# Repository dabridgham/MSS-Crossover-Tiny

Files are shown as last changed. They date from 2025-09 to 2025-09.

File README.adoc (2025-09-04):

= MSS Crossover

A KiCad project for a circuit board that implements an
https://www.modularsignalsystem.info/index.html[MSS] Detection node
(aka Crossover node).  It includes the block detection circuit and the
crossover wiring between two RJ45 connectors.

The block detection is implemented with a resistor as the current
sense element and then an ATtiny to do the math.  The board includes
the bridge rectifier so it can be powered off the ACC bus and it uses
optoisolators to drive the MSS line.

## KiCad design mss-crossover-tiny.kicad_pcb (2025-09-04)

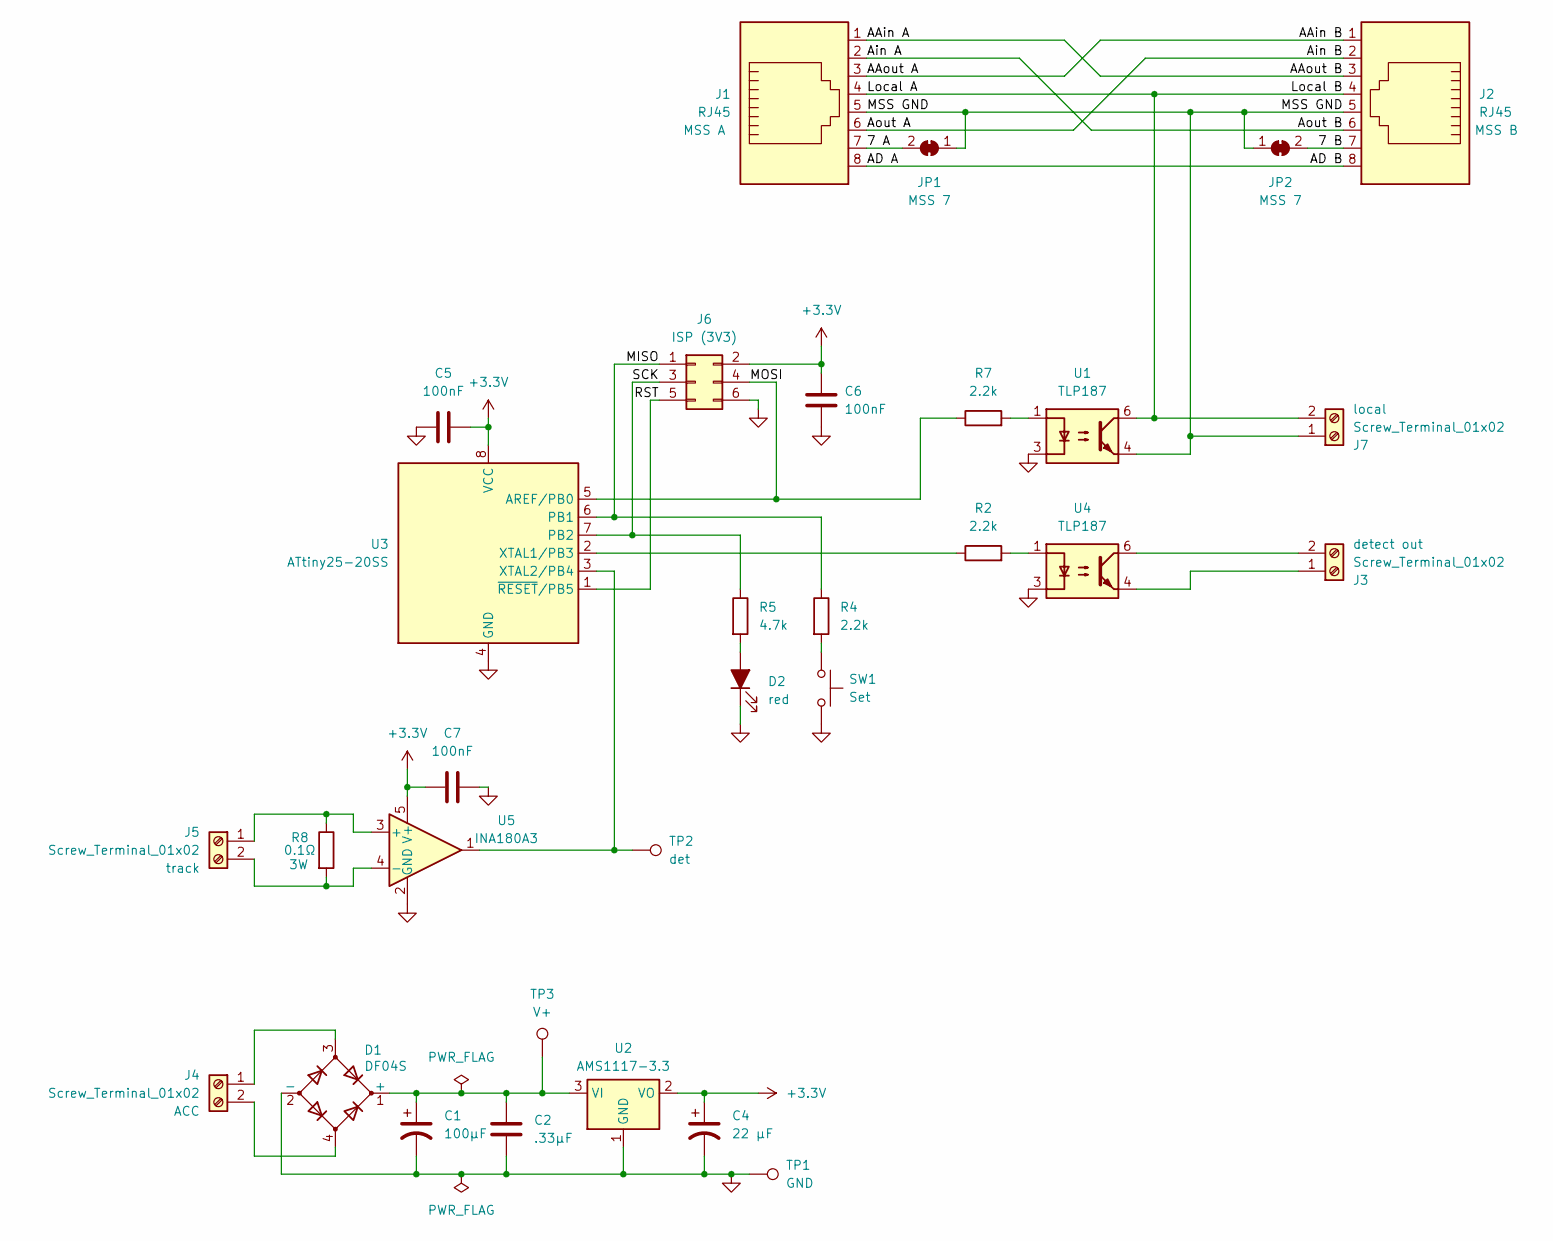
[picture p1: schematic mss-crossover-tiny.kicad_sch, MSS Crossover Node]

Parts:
C1: 100µF; CP_Elec_6.3x7.7; MPN EEV107M035A9HAA; JLCPCB Part C3338
C2: .33µF; C_0805_2012Metric_Pad1.18x1.45mm_HandSolder; MPN CL21B334KBFNNNE; JLCPCB Part C1737
C4: 22 µF; CP_EIA-3216-18_Kemet-A_Pad1.58x1.35mm_HandSolder; JLCPCB Part C7183
C5, C6, C7: 100nF; C_0805_2012Metric_Pad1.18x1.45mm_HandSolder; MPN CL21B104KBCNNNC
D1: DF04S; Diode_Bridge_Vishay_DFS; MPN DF04S; JLCPCB Part C5185986
D2: red; LED_0805_2012Metric_Pad1.15x1.40mm_HandSolder; MPN LTST-C170KRKT; JLCPCB Part C84256
J1, J2: RJ45; MJ3221-88; MPN MJ3221-88
J3, J4, J5, J7: Screw_Terminal_01x02; CUI_TB003-500-P02BE; MPN 691210910002
J6: ISP (3V3); Tag-Connect_TC2030-IDC-NL_2x03_P1.27mm_Vertical
JP1, JP2: MSS 7; SolderJumper-2_P1.3mm_Bridged_RoundedPad1.0x1.5mm
R2, R4, R7: 2.2k; R_0805_2012Metric_Pad1.20x1.40mm_HandSolder; MPN RC0805FR-102K2L
R5: 4.7k; R_0805_2012Metric_Pad1.20x1.40mm_HandSolder; MPN RC0805FR-104K7L
R8: 0.1Ω; R_2512_6332Metric; MPN CRA2512-FZ-R100ELF; JLCPCB Part C7419997
SW1: Set; SW_Push_1P1T_NO_CK_KMR2; MPN KMR211NG LFS; JLCPCB Part C72443
TP1: GND; TestPoint_THTPad_1.5x1.5mm_Drill0.7mm
TP2: det; TestPoint_THTPad_1.5x1.5mm_Drill0.7mm
TP3: V+; TestPoint_THTPad_1.5x1.5mm_Drill0.7mm
U1, U4: TLP187; SOIC-4_4.55x3.7mm_P2.54mm; MPN TLP187; JLCPCB Part C393886
U2: AMS1117-3.3; SOT-223-3_TabPin2; MPN AMS1117-3.3
U3: ATtiny25-20SS; SOIC-8_3.9x4.9mm_P1.27mm; MPN ATtiny25-20SSU
U5: INA180A3; SOT-23-5; MPN INA180A1IDBVR

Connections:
+3.3V: C4.1, C5.2, C6.2, C7.1, J6.2, U2.2 (VO), U3.8 (VCC), U5.5 (V+)
/7 A: J1.7, JP1.2 (B)
/7 B: J2.7, JP2.2 (B)
/AAin A: J1.1, J2.3
/AAin B: J1.3, J2.1
/AD A: J1.8, J2.8
/Ain A: J1.2, J2.6
/Ain B: J1.6, J2.2
/Local A: J1.4, J2.4, J7.2, U1.6
/MISO: J6.1, R4.1, U3.6 (PB1)
/MOSI: J6.4, R7.1, U3.5 (AREF/PB0)
/MSS GND: J1.5, J2.5, J7.1, JP1.1 (A), JP2.1 (A), U1.4
/RST: J6.5, U3.1 (~RESET/PB5)
/SCK: J6.3, R5.1, U3.7 (PB2)
GND: C1.2, C2.2, C4.2, C5.1, C6.1, C7.2, D1.2 (-), D2.1 (K), J6.6, SW1.1, TP1.1, U1.3, U2.1 (GND), U3.4 (GND), U4.3, U5.2 (GND)
unnamed: C1.1, C2.1, D1.1 (+), TP3.1, U2.3 (VI)
unnamed: D2.2 (A), R5.2
unnamed: J3.1, U4.4
unnamed: J3.2, U4.6
unnamed: D1.3, J4.1
unnamed: D1.4, J4.2
unnamed: J5.1, R8.1, U5.3 (+)
unnamed: J5.2, R8.2, U5.4 (-)
unnamed: R2.2, U4.1
unnamed: R4.2, SW1.2
unnamed: R7.2, U1.1
unnamed: R2.1, U3.2 (XTAL1/PB3)
unnamed: TP2.1, U3.3 (XTAL2/PB4), U5.1

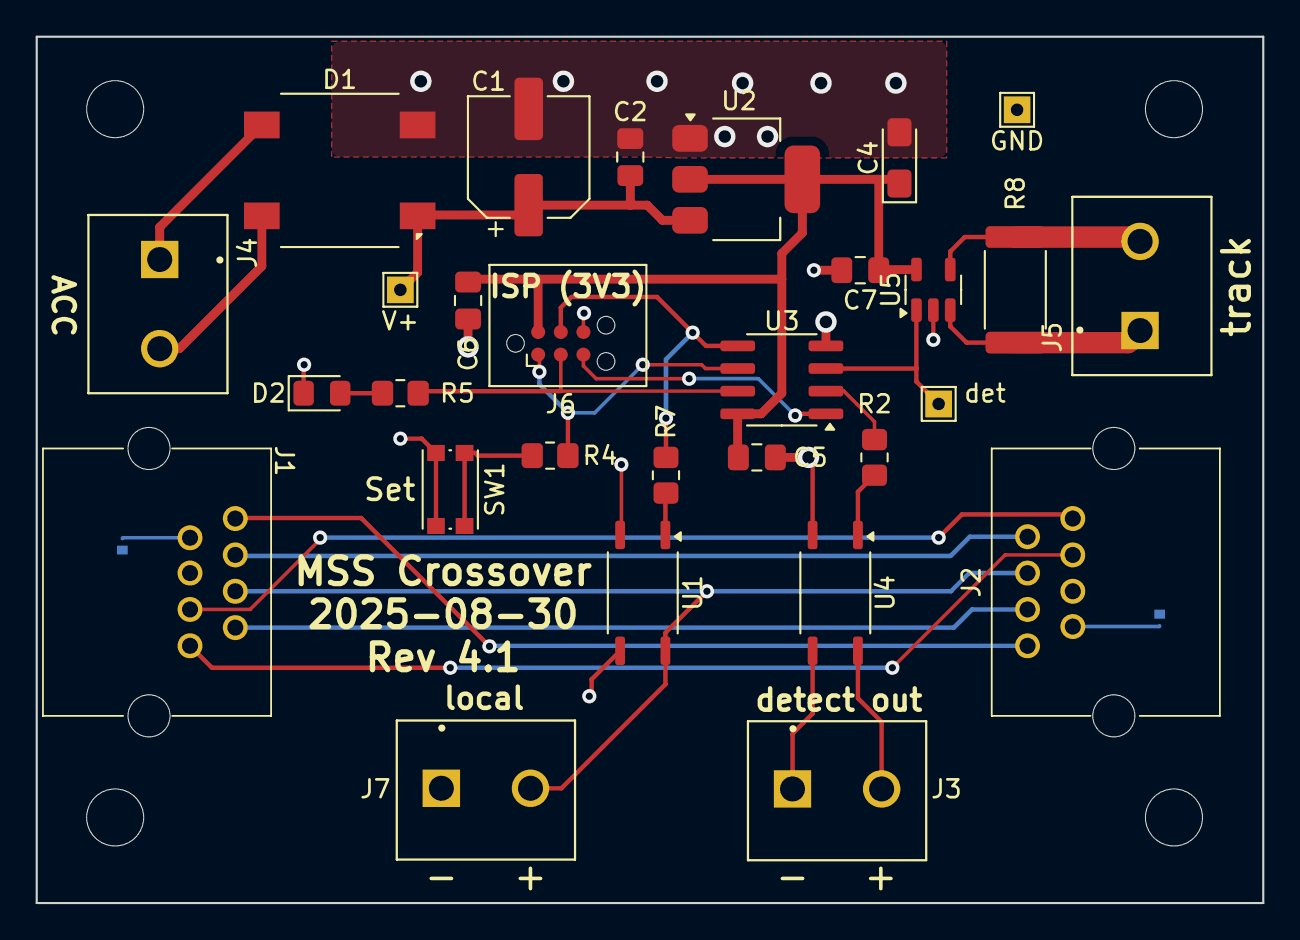
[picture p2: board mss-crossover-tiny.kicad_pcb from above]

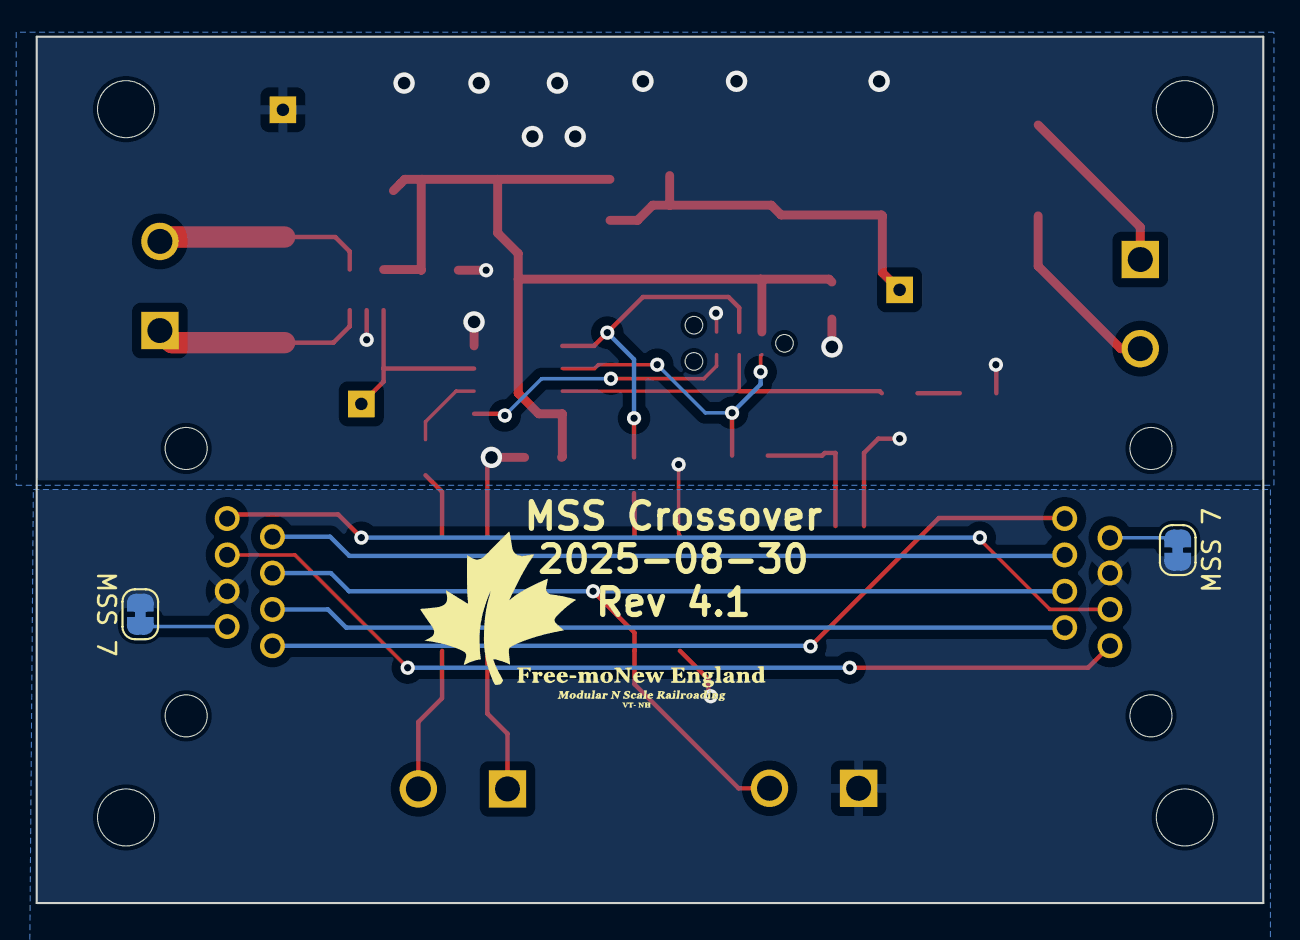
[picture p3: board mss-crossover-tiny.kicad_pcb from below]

Board: 2 copper layers, 68.8 x 48.6 mm, 31 parts (2 on the bottom side), 28 nets.

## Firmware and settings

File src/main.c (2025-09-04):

#define F_CPU 1000000UL		/* default internal clock is 1 MHz (8 MHz div 8) */
#include <avr/io.h>
#include <util/delay.h>
#include <avr/io.h>
#include <avr/interrupt.h>
#include <util/atomic.h>
#include <avr/eeprom.h>

 
#define bit(n) (1<<n)
#define bit_set(reg, bit) { reg |= (1<<bit); }
#define bit_clear(reg, bit) { reg &= ~(1<<bit); }

#define LED_ON() { bit_set(PORTB, PORTB2) }
#define LED_OFF() { bit_clear(PORTB, PORTB2) }

/* Control the LED, MSS, and detect outputs */
#define OUTPUT_ON() { PORTB |= bit(PORTB3) | bit(PORTB2) | bit(PORTB0); }
#define OUTPUT_OFF() { PORTB &= ~(bit(PORTB3) | bit(PORTB2) | bit(PORTB0)); }

#define BUTTON_PUSHED() (!bit_is_set(PINB, DDB1))

const int16_t attack = 100;
const int16_t decay = 10;
const int32_t filtern = 980;	/* filter numerator */
const int32_t filterd = 1000;	/* filter denominator */
const unsigned int timeout = 2000; /* 2 seconds */
const unsigned int sample_time = 2000; /* 2 seconds */
#define filter(old, new) (((old * filtern)/filterd) + (((new * (filterd-filtern))/filterd)))

uint16_t *threshold_p = 0; /* EEPROM address for the saved threshold */

/*
 * Timer interrupt code to implement a millis() function.
 */
volatile unsigned long timer0_millis = 0;

// Initialize the timer for 1ms interrupts
void millis_init(void) {
    // Set Timer0 to CTC mode with a prescaler of 64
    TCCR0A = (1 << WGM01);
    TCCR0B = (1 << CS01) | (1 << CS00); // Prescaler 64

    // Set compare value for 1ms at 16MHz: (16,000,000 / 64) / 1000 = 250
    // Set compare value for 1ms at 1MHz: (1,000,000 / 64) / 1000 = 16
    OCR0A = 16;

    // Enable compare match interrupt
    TIMSK |= (1 << OCIE0A);

    // Enable global interrupts
    sei();
}

// Timer0 compare match interrupt service routine
ISR(TIMER0_COMPA_vect) {
    timer0_millis++;
}

// Return the number of milliseconds since the program started
unsigned long millis(void) {
    unsigned long m;
    ATOMIC_BLOCK(ATOMIC_FORCEON) {
        m = timer0_millis;
    }
    return m;
}   

/* Setup the ADC */
void adc_init()
{
  ADMUX =		  // Vref = Vcc
    bit(ADLAR) |	  // left shifted
    0x2;		  // input is single-ended PB4 (ADC2)
  DIDR0 = bit(ADC2D);	  // disable the digital inputs on ADC2
  ADCSRB = bit(BIN);	  // bipolar input mode, free running mode
  ADCSRA = bit(ADEN) |	  // enable ADC
    //    bit(ADSC) |		// start conversion
    //    bit(ADATE) |		// auto trigger enable
    bit(ADPS2) | bit(ADPS1) | bit(ADPS0); // scale ADC clock by 128

  /* setup the ADC */
  ADMUX =		  // Vref = Vcc
    bit(ADLAR) |	  // left shifted
    0x2;		  // input is single-ended PB4 (ADC2)
  DIDR0 = bit(ADC2D);	  // disable the digital inputs on ADC2
  ADCSRB = bit(BIN);	  // bipolar input mode, free running mode
  ADCSRA = bit(ADEN) |	  // enable ADC
    //    bit(ADSC) |		// start conversion
    //    bit(ADATE) |		// auto trigger enable
    bit(ADPS2) | bit(ADPS1) | bit(ADPS0); // scale ADC clock by 128
}

/* Read the A/D Converter */
uint16_t read_adc()
{
  uint8_t c_low, c_hi;

  ADCSRA |= bit(ADSC);		   /* start conversion */
  while (bit_is_set(ADCSRA, ADSC)) /* wait for ADC to finish */
    ;				   /* should probably time out */

  /* must read low then high, per the datasheet */
  c_low = ADCL;
  c_hi = ADCH;
  return (c_hi << 8) | c_low;
}

int main()
{
  int16_t amps = 0,
    hi_amps = 0,
    threshold = 1000,
    setting_threshold = 0;
  unsigned long last_hi = 0,
    current_millis = 0;

  threshold = eeprom_read_word(threshold_p); /* read the stored threshold */

  millis_init();		/* enable the millisecond counter */

  // Set pins 5 (PB0), 7 (PB2), and 2 (PB3) as outputs, all others
  // inputs
  DDRB = bit(DDB0) | bit(DDB2) | bit(DDB3); 
  PORTB |= bit(DDB1);		/* enable pullup on pin 6 (PB1) for the pushbutton */

  adc_init();			/* setup the ADC */

  while (1) {
    current_millis = millis();
    if (setting_threshold) {
      if ((current_millis - last_hi) > sample_time) {
	threshold = (hi_amps * 15) / 10; /* set threshold 50% higher */
	eeprom_write_word(threshold_p, threshold);
	setting_threshold = 0;
	last_hi = 0;
	LED_OFF();
      } else {
	/* set hi_amps to the highest reading during the sample period */
	amps = read_adc();
	if (amps > hi_amps)
	  hi_amps = amps;
      }
    } else {
      if (BUTTON_PUSHED()) {
	setting_threshold = 1;
	last_hi = current_millis; /* use last_hi for the sample timeout */
	hi_amps = 0;
	LED_ON();
      } else {
	amps = read_adc();

	/* values greater than the threshold update the time */
	if (amps > threshold)
	  last_hi = current_millis;

	/* if the last high value was more recent than timeout, set detection outputs */
	if ((current_millis - last_hi) < timeout) {
	  OUTPUT_ON();
	} else {
	  OUTPUT_OFF();
	}

	_delay_ms(1);
      }
    }
  }
}

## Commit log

2023-11-03 Initial commit. The first prototype board is built and the software is in testing. The board is exhibiting far too much noise on Vcc and the output of the current sensor.
    [mss-crossover-tiny.kicad_pcb, mss-crossover-tiny.kicad_sch]
2023-11-04 Added test points to board. In src, added code to control the opto-isolator as well as the LED.
    [mss-crossover-tiny.kicad_pcb, mss-crossover-tiny.kicad_sch]
2023-11-04 Updated some of the MPNs
    [mss-crossover-tiny.kicad_sch]
2023-11-06 Updated MPN for the ATtiny
    [mss-crossover-tiny.kicad_sch]
2023-11-14 Made some macros to simplify code and moved the adc read into a subroutine.
2023-11-14 Changed to be able to plug the crossover board into a cascade board.
    [mss-crossover-tiny.kicad_pcb, mss-crossover-tiny.kicad_sch]
2023-11-25 Little updates. Moved power from 12V to ACC back to 12V.
    [mss-crossover-tiny.kicad_pcb, mss-crossover-tiny.kicad_sch]
2024-03-23 Reworked design to use a current shunt instead.
    [mss-crossover-tiny.kicad_pcb, mss-crossover-tiny.kicad_sch]
2025-02-25 Still working on then redesign for a resistive sense element. Also added optoisolators.
    [mss-crossover-tiny.kicad_pcb, mss-crossover-tiny.kicad_sch]
2025-02-25 Changed everything to 3.3V instead of 5V
    [mss-crossover-tiny.kicad_pcb, mss-crossover-tiny.kicad_sch]
2025-03-03 Updated to KiCad v9. This is the release that was sent to JLCPCB for assembly as version 4.0.
    [mss-crossover-tiny.kicad_pcb, mss-crossover-tiny.kicad_sch]
2025-09-04 Some small changes learned from the first prototype. Switch back to the larger screw terminals and changed resistor to the pushbutton to 2.2k instead of 4.7k.
    [mss-crossover-tiny.kicad_pcb, mss-crossover-tiny.kicad_sch]
2025-09-04 Changed the code to work with the shunt current detection.
2025-09-04 Fixed up the threshold calculation and added reading/writing to/from the EEPROM.
    [main.c]
